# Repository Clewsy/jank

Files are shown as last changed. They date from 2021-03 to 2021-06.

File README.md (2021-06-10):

# jank

jank is **j**ust **an**other **k**eypad.  Specifically it is a USB numeric keypad with some macro buttons.  It's kind of an evolution of another project ([macro][link_gitlab_macr0]).

Additional photos and detail can be found at [clews.pro][link_clews_jank] and [hackaday.io][link_hackaday.io_jank].

Features include:
* Uses a USB type C connector (configured to identify as a USB 2.0 device).
* 21 keys total - 17 keys configured in a standard keypad arrangement, plus an addition row of four keys across the top.
* All 21 keys can be configured as any reguglar keyboard keystroke (including media control keys) or a programmable macro.
* The keys are all mechanical keyswitches - I used gateron blues which are pin-comnpatible with [Cherry MX][link_web_cherry_mx] keyswitches.
* All the keyswitches are plate-mounted with a laser-cut stainless steel plate.  The larger '+', '0' and "Enter" keys all have cherry-style, plate-mounted stabilizers.
* There is a 3mm led beneath each keyswitch so that the legends are all back-lit.
* The LEDs are powered via a boost controller (MP3202) which is enabled by a PWM signal from the microcontroller - this allows variable brightness.  Brightness is set by a tact switch on the bottom of the unit.  Pushing the switch cycles the LEDs from off through increasing levels of brightness and a pulsing effect with three different speeds.
* There is a single smd LED on the bottom of the unit that is programmed to function as the NUM LOCK indicator.

Although any key can be configured to function as any keystroke or macro, I use jank with my laptop as a traditional numerical keypad.  Only the top four keys are configured as macros.

Proudly mentioned at [hackaday.com][link_hackaday_jank].

*********************************

To do:

- [X] Hardware
    - [X] Parts selection.
    - [X] Schematic design.
    - [X] PCB layout design.
    - [X] Parts order.
    - [X] PCB assembly.
    - [X] Enclosure.
- [X] Firmware
    - [X] LED control.
    - [X] Regular keystrokes.
    - [X] Num lock LED.
    - [X] Simple macros.
    - [X] Complex macros.

*********************************

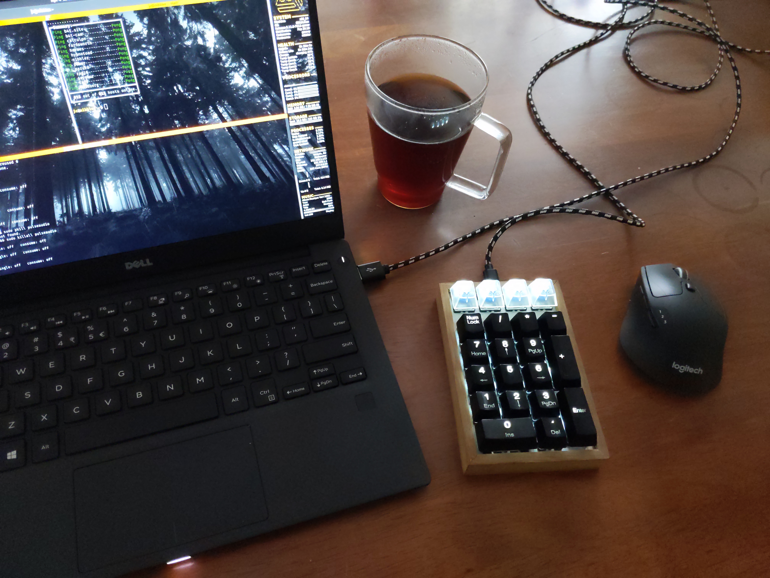
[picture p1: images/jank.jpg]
The completed jank.


[link_clews_jank]:https://clews.pro/projects/jank.php
[link_gitlab_macr0]:https://gitlab.com/clewsy/macr0
[link_hackaday_jank]:https://hackaday.com/2021/06/08/custom-num-pad-does-double-duty-as-macro-pad/
[link_hackaday.io_jank]:https://hackaday.io/project/180104-jank
[link_web_cherry_mx]:https://www.cherrymx.de/en

[image_jank]:images/jank.jpg

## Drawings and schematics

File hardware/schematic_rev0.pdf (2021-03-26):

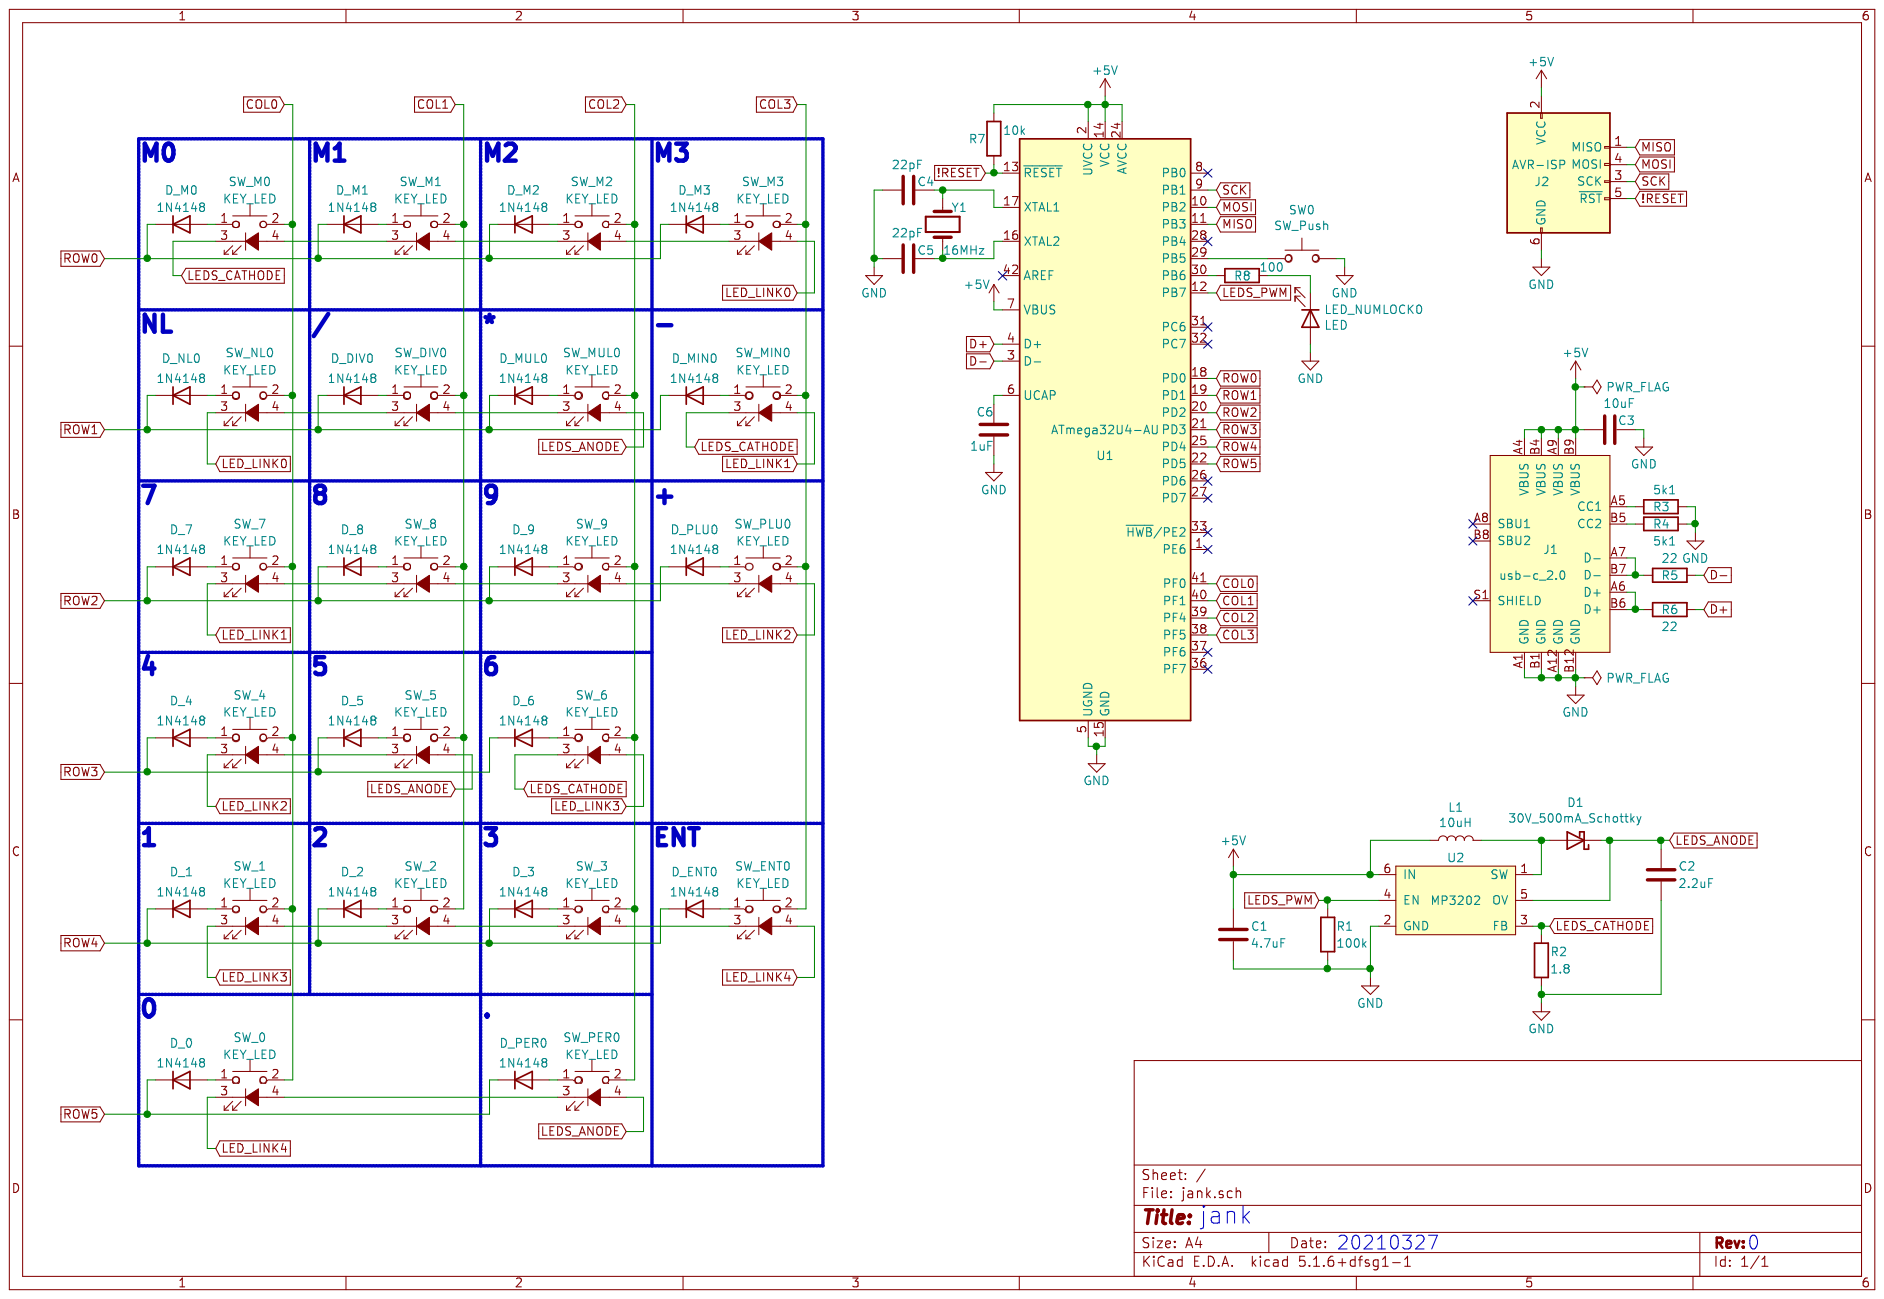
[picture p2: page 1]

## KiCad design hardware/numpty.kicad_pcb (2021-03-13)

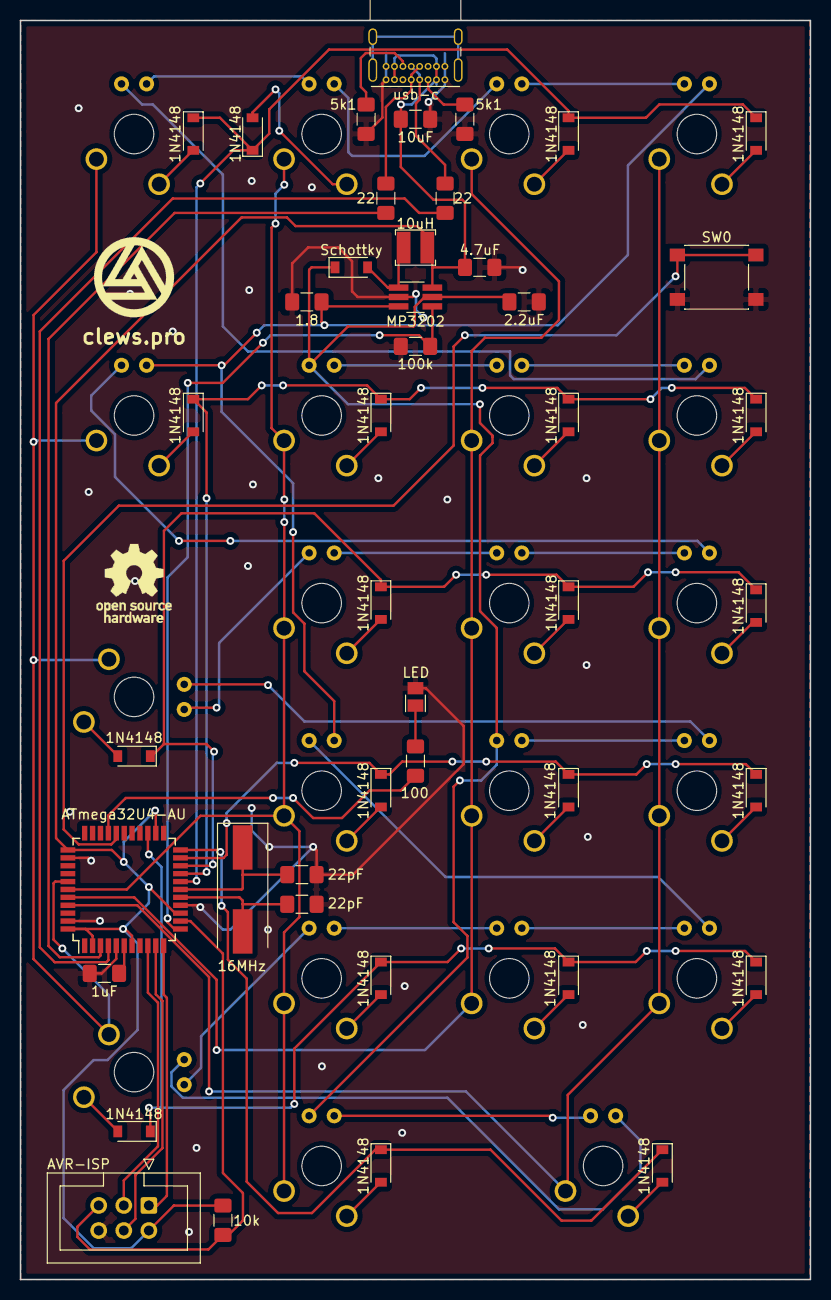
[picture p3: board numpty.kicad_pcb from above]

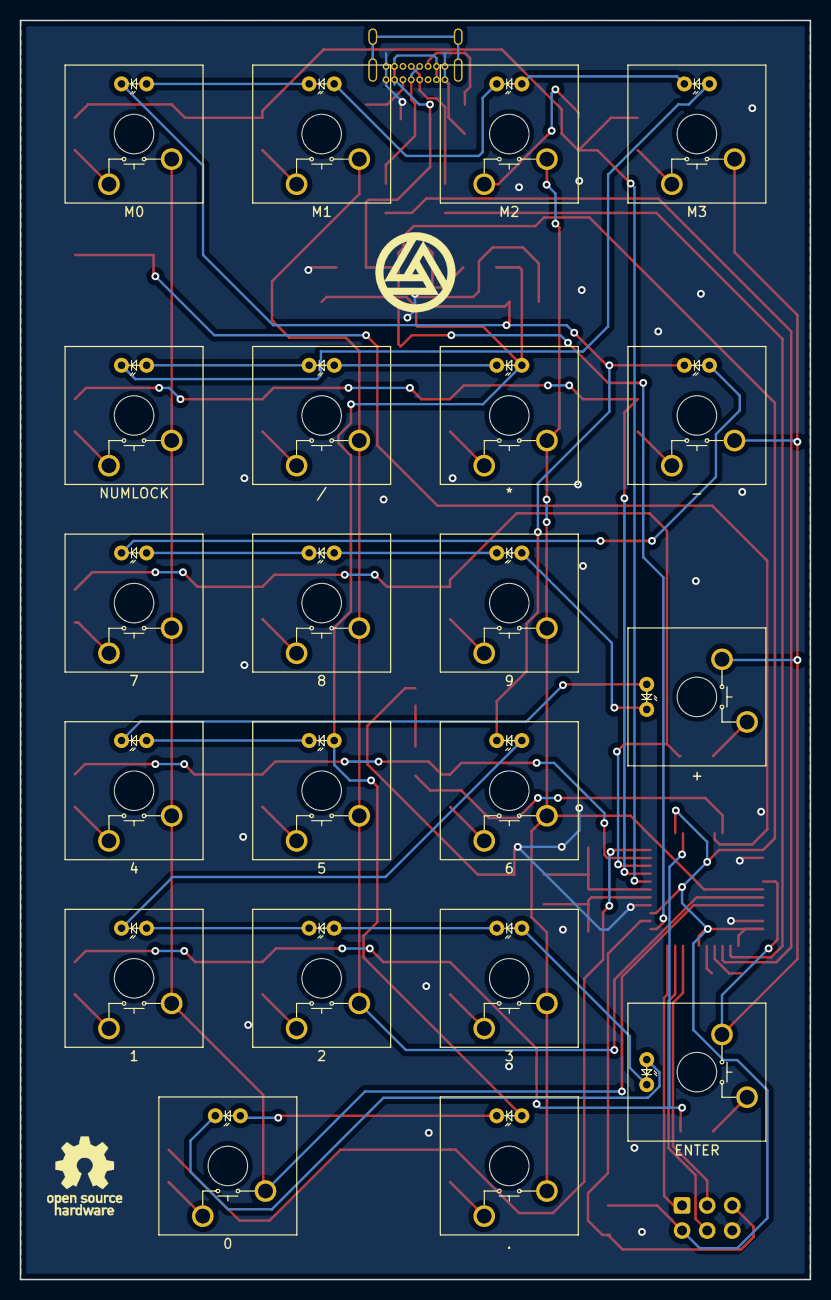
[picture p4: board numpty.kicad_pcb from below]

Board: 2 copper layers, 80.0 x 127.5 mm, 65 parts (21 on the bottom side), 71 nets.

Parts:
0, 1, 2, 3, 4, 5, 6, 7, 8, 9, .: KEY_LED; Gateron_LED_1.00u_Plate
*: KEY_LED; Gateron_LED_1.00u_Plate
+: KEY_LED; Gateron_LED_1.00u_Plate
-: KEY_LED; Gateron_LED_1.00u_Plate
/: KEY_LED; Gateron_LED_1.00u_Plate
C1: 4.7uF; C_1206_3216Metric_Pad1.42x1.75mm_HandSolder
C2: 2.2uF; C_1206_3216Metric_Pad1.42x1.75mm_HandSolder
C3: 10uF; C_1206_3216Metric_Pad1.42x1.75mm_HandSolder
C4, C5: 22pF; C_1206_3216Metric_Pad1.42x1.75mm_HandSolder
C6: 1uF; C_1206_3216Metric_Pad1.42x1.75mm_HandSolder
D1: Schottky; D_SOD-123
D_0, D_1, D_2, D_3, D_4, D_5, D_6, D_7, D_8, D_9: 1N4148; D_SOD-123
D_DIV0: 1N4148; D_SOD-123
D_ENT0: 1N4148; D_SOD-123
D_M0, D_M1, D_M2, D_M3: 1N4148; D_SOD-123
D_MIN0: 1N4148; D_SOD-123
D_MUL0: 1N4148; D_SOD-123
D_NL0: 1N4148; D_SOD-123
D_PER0: 1N4148; D_SOD-123
D_PLU0: 1N4148; D_SOD-123
ENTER: KEY_LED; Gateron_LED_1.00u_Plate
J1: usb-c; USB_C_Receptacle_GCT_USB4085
J2: AVR-ISP; IDC-Header_2x03_P2.54mm_Vertical
L1: 10uH; SRN3010TA
LED_NUMLOCK0: LED; LED_Cree-XQ_HandSoldering
M0, M1, M2, M3: KEY_LED; Gateron_LED_1.00u_Plate
NUMLOCK: KEY_LED; Gateron_LED_1.00u_Plate
R1: 100k; R_1206_3216Metric_Pad1.42x1.75mm_HandSolder
R2: 1.8; R_1206_3216Metric_Pad1.42x1.75mm_HandSolder
R3, R4: 5k1; R_1206_3216Metric_Pad1.42x1.75mm_HandSolder
R5, R6: 22; R_1206_3216Metric_Pad1.42x1.75mm_HandSolder
R7: 10k; R_1206_3216Metric_Pad1.42x1.75mm_HandSolder
R8: 100; R_1206_3216Metric_Pad1.42x1.75mm_HandSolder
SW0: SW_Push; SW_Push_1P1T_NO_6x6mm_H9.5mm
U1: ATmega32U4-AU; TQFP-44_10x10mm_P0.8mm
U2: MP3202; TSOT-23-6_HandSoldering
Y1: 16MHz; Crystal_SMD_HC49-SD

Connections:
!RESET: J2.5, R7.2, U1.13
+5V: C1.1, C3.1, J1.A4, J1.A9, J1.B4, J1.B9, J2.2, L1.1, R7.1, U1.2, U1.7, U1.14, U1.24, U1.34, U1.44, U2.6
COL0: 0.2, 1.2, 4.2, 7.2, M0.2, NUMLOCK.2, U1.41
COL1: 2.2, 5.2, 8.2, /.2, M1.2, U1.40
COL2: 3.2, 6.2, 9.2, *.2, ..2, M2.2, U1.39
COL3: +.2, -.2, ENTER.2, M3.2, U1.38
D+: R6.1, U1.4
D-: R5.1, U1.3
GND: C1.2, C2.2, C3.2, C4.2, C5.2, C6.1, J1.A1, J1.A12, J1.B1, J1.B12, J2.6, LED_NUMLOCK0.2, R1.2, R2.2, R3.1, R4.1, SW0.2, U1.5, U1.15, U1.23, U1.35, U1.43, U2.2
LEDS_ANODE: 5.4, *.4, ..4, C2.1, D1.1, U2.5
LEDS_CATHODE: 6.3, -.3, M0.3, R2.1, U2.3
LEDS_PWM: R1.1, U1.12, U2.4
LED_LINK0: M3.4, NUMLOCK.3
LED_LINK1: 7.3, -.4
LED_LINK2: 4.3, +.4
LED_LINK3: 1.3, 6.4
LED_LINK4: 0.3, ENTER.4
MISO: J2.1, U1.11
MOSI: J2.4, U1.10
unnamed: C4.1, U1.17, Y1.1
unnamed: C5.1, U1.16, Y1.2
unnamed: C6.2, U1.6
unnamed: D1.2, L1.2, U2.1
unnamed: 0.1, D_0.2
unnamed: 1.1, D_1.2
unnamed: 2.1, D_2.2
unnamed: 3.1, D_3.2
unnamed: 4.1, D_4.2
unnamed: 5.1, D_5.2
unnamed: 6.1, D_6.2
unnamed: 7.1, D_7.2
unnamed: 8.1, D_8.2
unnamed: 9.1, D_9.2
unnamed: /.1, D_DIV0.2
unnamed: D_ENT0.2, ENTER.1
unnamed: D_M0.2, M0.1
unnamed: D_M1.2, M1.1
unnamed: D_M2.2, M2.1
unnamed: D_M3.2, M3.1
unnamed: -.1, D_MIN0.2
unnamed: *.1, D_MUL0.2
unnamed: D_NL0.2, NUMLOCK.1
unnamed: ..1, D_PER0.2
unnamed: +.1, D_PLU0.2
unnamed: J1.A5, R3.2
unnamed: J1.A6, J1.B6, R6.2
unnamed: J1.A7, J1.B7, R5.2
unnamed: J1.B5, R4.2
unnamed: LED_NUMLOCK0.1, R8.1
unnamed: R8.2, U1.30
unnamed: SW0.1, U1.29
unnamed: 0.4, ..3
unnamed: 1.4, 2.3
unnamed: 2.4, 3.3
unnamed: 3.4, ENTER.3
unnamed: 4.4, 5.3
unnamed: 7.4, 8.3
unnamed: 8.4, 9.3
unnamed: 9.4, +.3
unnamed: /.3, NUMLOCK.4
unnamed: *.3, /.4
unnamed: M0.4, M1.3
unnamed: M1.4, M2.3
unnamed: M2.4, M3.3
ROW0: D_M0.1, D_M1.1, D_M2.1, D_M3.1, U1.18
ROW1: D_DIV0.1, D_MIN0.1, D_MUL0.1, D_NL0.1, U1.19
ROW2: D_7.1, D_8.1, D_9.1, D_PLU0.1, U1.20
ROW3: D_4.1, D_5.1, D_6.1, U1.21
ROW4: D_1.1, D_2.1, D_3.1, D_ENT0.1, U1.25
ROW5: D_0.1, D_PER0.1, U1.22
SCK: J2.3, U1.9

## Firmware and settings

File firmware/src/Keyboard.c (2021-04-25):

// This version of Keyboard.c has been heavily modified from the original demo in Dean Camera's LUFA repository.
// Effectively I have used combinations of my own functions in addition to functions from the following .c files:
// - Keyboard.c at https://github.com/abcminiuser/lufa/tree/790ac4d125c1c5d72016b52c2b9ad58f5e5f8c62/Demos/Device/LowLevel/Keyboard
// - KeyboardMouse.c at https://github.com/abcminiuser/lufa/tree/790ac4d125c1c5d72016b52c2b9ad58f5e5f8c62/Demos/Device/LowLevel/KeyboardMouse
// - MediaController.c at https://github.com/abcminiuser/lufa/tree/790ac4d125c1c5d72016b52c2b9ad58f5e5f8c62/Projects/MediaController
// These changes are similarly MIT licensed (refer license at https://gitlab.com/clewsy/jank).

/*
             LUFA Library
     Copyright (C) Dean Camera, 2020.

  dean [at] fourwalledcubicle [dot] com
           www.lufa-lib.org
*/

/*
  Copyright 2020  Dean Camera (dean [at] fourwalledcubicle [dot] com)
  Copyright 2010  Denver Gingerich (denver [at] ossguy [dot] com)

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
  The author disclaims all warranties with regard to this
  software, including all implied warranties of merchantability
  and fitness.  In no event shall the author be liable for any
  special, indirect or consequential damages or any damages
  whatsoever resulting from loss of use, data or profits, whether
  in an action of contract, negligence or other tortious action,
  arising out of or in connection with the use or performance of
  this software.
*/

#include "Keyboard.h"

// Indicates what report mode the host has requested, true for normal HID reporting mode, false for special boot protocol reporting
// mode.
static bool UsingReportProtocol = true;

// Current Idle period. This is set by the host via a Set Idle HID class request to silence the device's reports for either the
// entire idle duration, or until the report status changes (e.g. the user presses a key).
static uint16_t IdleCount = 500;

// Current Idle period remaining. When the IdleCount value is set, tracks the remaining number of idle milliseconds. This is
// separate to the IdleCount timer and is incremented and compared as the host may request the current idle period via a Get Idle
// HID class request, thus its value must be preserved.
static uint16_t IdleMSRemaining = 0;

// Declaration of a keyscan_report_t structure that will be used to pass current keypresses to the keyboard reports and the media
// controller reports. 
static keyscan_report_t keyscan_report;

// Configures the board hardware and chip peripherals.
// Use case is specifically an ATmega32U4 (ARCH_AVR8).
void SetupHIDHardware(void)
{
	// Disable watchdog if enabled by bootloader/fuses.
	MCUSR &= ~(1 << WDRF);
	wdt_disable();

	// Set numlock LED pin as an output.
	NUMLOCK_LED_DDR |= (1 << NUMLOCK_LED);

	// USB Initialization from LUFA library.
	USB_Init();
}

// Event handler for the USB_Connect event. This indicates that the device is enumerating via the status LEDs and starts the library
// USB task to begin the enumeration and USB management process.
void EVENT_USB_Device_Connect(void)
{
	// Indicate USB enumerating with NUMLOCK LED.
	numlock_led(true);

	// Default to report protocol on connect.
	UsingReportProtocol = true;
}

// Event handler for the USB_Disconnect event. This indicates that the device is no longer connected to a host.
void EVENT_USB_Device_Disconnect(void)
{
	// Indicate USB not ready.
	numlock_led(false);
}

// Event handler for the USB_ConfigurationChanged event. This is fired when the host sets the current configuration of the USB
// device after enumeration, and configures the keyboard device endpoints.
void EVENT_USB_Device_ConfigurationChanged(void)
{
	bool ConfigSuccess = true;

	// Setup HID Report Endpoints.
	ConfigSuccess &= Endpoint_ConfigureEndpoint(KEYBOARD_IN_EPADDR, EP_TYPE_INTERRUPT, HID_EPSIZE, 1);
	ConfigSuccess &= Endpoint_ConfigureEndpoint(KEYBOARD_OUT_EPADDR, EP_TYPE_INTERRUPT, HID_EPSIZE, 1);
	ConfigSuccess &= Endpoint_ConfigureEndpoint(MEDIACONTROLLER_IN_EPADDR, EP_TYPE_INTERRUPT, HID_EPSIZE, 1);

	// Turn on Start-of-Frame events for tracking HID report period expiry.
	USB_Device_EnableSOFEvents();
}
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

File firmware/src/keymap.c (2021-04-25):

#include "keymap.h"

// This enabled keymap.h configuration does not use macros.  The numerical keypad is configured as a numerical keypad and the four
// top row keys are configured for media control.  See the commented section below for example macro configurations. 

// Define the physical row and column pins on the microcontroller to be scanned for key presses.
const uint8_t key_row_array[]	= {ROW0, ROW1, ROW2, ROW3, ROW4, ROW5};
const uint8_t key_col_array[]	= {COL0, COL1, COL2, COL3};
const uint8_t macro_row_array[]	= {};
const uint8_t macro_col_array[]	= {};

// Number pad key definitions.
// KEY_X_Y where X:Row Number, Y:Column Number.
#define KEY_0_0 HID_MEDIACONTROLLER_SC_TOGGLE
#define KEY_0_1 HID_MEDIACONTROLLER_SC_STOP
#define KEY_0_2 HID_MEDIACONTROLLER_SC_PREVIOUS
#define KEY_0_3 HID_MEDIACONTROLLER_SC_NEXT
#define KEY_1_0 HID_KEYBOARD_SC_NUM_LOCK
#define KEY_1_1 HID_KEYBOARD_SC_KEYPAD_SLASH
#define KEY_1_2 HID_KEYBOARD_SC_KEYPAD_ASTERISK
#define KEY_1_3 HID_KEYBOARD_SC_KEYPAD_MINUS
#define KEY_2_0 HID_KEYBOARD_SC_KEYPAD_7_AND_HOME
#define KEY_2_1 HID_KEYBOARD_SC_KEYPAD_8_AND_UP_ARROW
#define KEY_2_2 HID_KEYBOARD_SC_KEYPAD_9_AND_PAGE_UP
#define KEY_2_3 HID_KEYBOARD_SC_KEYPAD_PLUS
#define KEY_3_0 HID_KEYBOARD_SC_KEYPAD_4_AND_LEFT_ARROW
#define KEY_3_1 HID_KEYBOARD_SC_KEYPAD_5
#define KEY_3_2 HID_KEYBOARD_SC_KEYPAD_6_AND_RIGHT_ARROW
#define KEY_3_3 0x00	// No key here.
#define KEY_4_0 HID_KEYBOARD_SC_KEYPAD_1_AND_END
#define KEY_4_1 HID_KEYBOARD_SC_KEYPAD_2_AND_DOWN_ARROW
#define KEY_4_2 HID_KEYBOARD_SC_KEYPAD_3_AND_PAGE_DOWN
#define KEY_4_3 HID_KEYBOARD_SC_KEYPAD_ENTER
#define KEY_5_0 HID_KEYBOARD_SC_KEYPAD_0_AND_INSERT
#define KEY_5_1 0x00	// No key here.
#define KEY_5_2 HID_KEYBOARD_SC_KEYPAD_DOT_AND_DELETE
#define KEY_5_3 0x00	// No key here.

// The key map array - for regular key strokes including media control keys.
const char KEYMAP[MAX_NUM_KEY_ROWS][MAX_NUM_KEY_COLS] PROGMEM = {
	//Col 0   Col 1    Col 2    Col 3
	{KEY_0_0, KEY_0_1, KEY_0_2, KEY_0_3}, // Row 0
	{KEY_1_0, KEY_1_1, KEY_1_2, KEY_1_3}, // Row 1
	{KEY_2_0, KEY_2_1, KEY_2_2, KEY_2_3}, // Row 2
	{KEY_3_0, KEY_3_1, KEY_3_2, KEY_3_3}, // Row 3
	{KEY_4_0, KEY_4_1, KEY_4_2, KEY_4_3}, // Row 4
	{KEY_5_0, KEY_5_1, KEY_5_2, KEY_5_3}  // Row 5
};

// The macro map array - for key strokes that are mapped as macros.
const macro_t MACROMAP[MAX_NUM_MACRO_ROWS][MAX_NUM_MACRO_COLS][MAX_MACRO_ACTIONS] PROGMEM = {};



////////////////////////////////////////////////////////////////////////////////////////////////////////////////////////////////////
////////// keymap.h demonstration //////////////////////////////////////////////////////////////////////////////////////////////////
////////////////////////////////////////////////////////////////////////////////////////////////////////////////////////////////////

/*

// Define the physical row and column pins on the microcontroller to be scanned for key presses.
const uint8_t key_row_array[]	= {ROW1, ROW2, ROW3, ROW4, ROW5};
const uint8_t key_col_array[]	= {COL0, COL1, COL2, COL3};
const uint8_t macro_row_array[]	= {ROW0};
const uint8_t macro_col_array[]	= {COL0, COL1, COL2, COL3};

// Number pad key definitions.
// KEY_X_Y where X:Row Number, Y:Column Number.
#define KEY_1_0 HID_KEYBOARD_SC_NUM_LOCK
#define KEY_1_1 HID_KEYBOARD_SC_KEYPAD_SLASH
#define KEY_1_2 HID_KEYBOARD_SC_KEYPAD_ASTERISK
#define KEY_1_3 HID_KEYBOARD_SC_KEYPAD_MINUS
#define KEY_2_0 HID_KEYBOARD_SC_KEYPAD_7_AND_HOME
#define KEY_2_1 HID_KEYBOARD_SC_KEYPAD_8_AND_UP_ARROW
#define KEY_2_2 HID_KEYBOARD_SC_KEYPAD_9_AND_PAGE_UP
#define KEY_2_3 HID_KEYBOARD_SC_KEYPAD_PLUS
#define KEY_3_0 HID_KEYBOARD_SC_KEYPAD_4_AND_LEFT_ARROW
#define KEY_3_1 HID_KEYBOARD_SC_KEYPAD_5
#define KEY_3_2 HID_KEYBOARD_SC_KEYPAD_6_AND_RIGHT_ARROW
#define KEY_3_3 0x00	// No key here.
#define KEY_4_0 HID_KEYBOARD_SC_KEYPAD_1_AND_END
#define KEY_4_1 HID_KEYBOARD_SC_KEYPAD_2_AND_DOWN_ARROW
#define KEY_4_2 HID_KEYBOARD_SC_KEYPAD_3_AND_PAGE_DOWN
#define KEY_4_3 HID_KEYBOARD_SC_KEYPAD_ENTER
#define KEY_5_0 HID_KEYBOARD_SC_KEYPAD_0_AND_INSERT
#define KEY_5_1 0x00	// No key here.
#define KEY_5_2 HID_KEYBOARD_SC_KEYPAD_DOT_AND_DELETE
#define KEY_5_3 0x00	// No key here.

// The key map array - for regular key strokes including media control keys.
const char KEYMAP[MAX_NUM_KEY_ROWS][MAX_NUM_KEY_COLS] PROGMEM = {
	//Col 0   Col 1    Col 2    Col 3
//	{KEY_0_0, KEY_0_1, KEY_0_2, KEY_0_3}, // Row 0
	{KEY_1_0, KEY_1_1, KEY_1_2, KEY_1_3}, // Row 1
	{KEY_2_0, KEY_2_1, KEY_2_2, KEY_2_3}, // Row 2
	{KEY_3_0, KEY_3_1, KEY_3_2, KEY_3_3}, // Row 3
	{KEY_4_0, KEY_4_1, KEY_4_2, KEY_4_3}, // Row 4
	{KEY_5_0, KEY_5_1, KEY_5_2, KEY_5_3}  // Row 5
};

// The macro map array - for key strokes that are mapped as macros.
const macro_t MACROMAP[MAX_NUM_MACRO_ROWS][MAX_NUM_MACRO_COLS][MAX_MACRO_ACTIONS] PROGMEM =
{
	{ //Row0
		{ //Col0
			{M_KEYS, {HID_KEYBOARD_SC_F12}},	// This macro is just the same as hitting the F12 key.
		},
		{ //Col1
			{M_KEYS, {HID_KEYBOARD_SC_LEFT_GUI}},	// This macro will go to the specified url in a new firefox tab.
			{M_WAIT, {1}},
			{M_STRING, "firefox" },
			{M_KEYS, {HID_KEYBOARD_SC_ENTER}},
			{M_WAIT, {2}},
			{M_KEYS, {HID_KEYBOARD_SC_LEFT_CONTROL, HID_KEYBOARD_SC_T}},
			{M_STRING, "https://clews.pro/projects/jank.php" },
			{M_KEYS, {HID_KEYBOARD_SC_ENTER}},
		},
		{ //Col2
			{M_STRING, "      _\n"},	// This macro will enter a series of strings to create some ascii art.
			{M_STRING, "     ( )\n"},
			{M_STRING, "      H\n"},
			{M_STRING, "      H\n"},
			{M_STRING, "     _H_\n"},
			{M_STRING, "  .-'-.-'-.\n"},
			{M_STRING, " /         \\\n"},
			{M_STRING, "|           |\n"},
			{M_STRING, "|   .-------'._\n"},
			{M_STRING, "|  / /  '.' '. \\\n"},
			{M_STRING, "|  \\ \\ @   @ / /\n"},
			{M_STRING, "|   '---------'\n"},
			{M_STRING, "|    _______|\n"},
			{M_STRING, "|  .'-+-+-+|\n"},
			{M_STRING, "|  '.-+-+-+|\n"},
			{M_STRING, "|    '''''' |\n"},
			{M_STRING, "'-.__   __.-'\n"},
			{M_STRING, "     '''\n"}
		},
		{ //Col3
			{M_STRING, "Bender is Great!" },	// This macro will type a string of characters then hit enter.
			{M_KEYS, {HID_KEYBOARD_SC_ENTER}},
		}
	}
};
*/


/*
Row and column configuration of the jank keypad.

	 COL0 COL1 COL2 COL3
	_____________________
	|    |    |    |    |
ROW0	| 00 | 01 | 02 | 03 |
	|____|____|____|____|
	_____________________
	|    |    |    |    |
ROW1	| 10 | 11 | 12 | 13 |
	|____|____|____|____|
	|    |    |    |    |
ROW2	| 20 | 21 | 22 | 23 |
	|____|____|____|    |
	|    |    |    |    |
ROW3	| 30 | 31 | 32 |    |
	|____|____|____|____|
	|    |    |    |    |
ROW4	| 40 | 41 | 42 | 43 |
	|____|____|____|    |
	|         |    |    |
ROW5	| 50      | 52 |    |
	|_________|____|____|

*/

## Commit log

2021-03-08 Begun working on the schematic.
    [numpty.kicad_pcb, numpty.sch]
2021-03-08 Added diode spec.
2021-03-08 Rev_0 schematic finished, first pass at PCB layout (no traces yet).
    [numpty.sch]
2021-03-08 Run traces and fills.
    [numpty.kicad_pcb]
2021-03-08 Started tidy up (silk screen etc).
    [numpty.kicad_pcb]
2021-03-12 Moved led pins to port B. Added push-button on port B. Reworked layout to suit these changes.
    [numpty.kicad_pcb, numpty.sch]
2021-03-13 Cleaned up rev 0 PCB layout, ordered fabrication. Added .gitignore.
    [numpty.kicad_pcb, numpty.sch]
2021-03-14 Added pdf of schematic.
2021-03-26 Renaming project and repo from numpty to jank.
    [jank.kicad_pcb, jank.sch, numpty.sch]
2021-03-27 Partially assembled. Testing with code from macr0 - just configured to test LED pulsing, no USB yet.
2021-03-27 Datasheet for the smd LED.
2021-03-28 SMD LED now acts as numlock indicator. Some comments and tidy-up.
2021-03-28 Adjusted de-bounce. Comments.
2021-03-28 What a dummy, the LED was backwards.
2021-04-25 Changed ifs to switch/case. Fixed media control key op. Changed default enabled keymaps.
    [Keyboard.c, keymap.c, keymap.h]
